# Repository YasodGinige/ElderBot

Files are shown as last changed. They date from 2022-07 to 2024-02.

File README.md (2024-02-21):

# ElderBot
### Elder Monitoring and Accident Warning System

In recent years, the risk of falling, especially among the aging population, has been propelled by the rising prevalence of various chronic diseases such as Alzheimer’s and Dementia along with the increasing incidence of chronic disorders such as diabetes, chronic obstructive pulmonary disease (COPD), cardiovascular diseases, etc. Implementation of fall detection systems is vital because falls are risky especially for individuals who live alone in their homes. According to the World Health Organization1, about 28% - 35% of individuals over the age of 65 are projected to go through one fall at a minimum each year, and this danger rises to 42% for individuals over the age of 70. Such a situation impels the necessity for fall detection systems. Fall detection systems can mitigate some of the adverse consequences of a fall. One major outcome of a fall is a bone fracture, for instance, a fracture of the hip, femur, forearm, leg, or ankle bone. Immediate medical intervention could effectively prevent serious deterioration of bodily functions. Through this project, we develop ElderBOT, a wearable fall detection device with an alert system that utilizes 3 modes of notifications in case of an emergency. Our product is a reliable, effective, and cost-efficient device designed to cater to user requirements.

Project video: https://drive.google.com/file/d/1kUZlkXkYoyiRHa6RiEkOUjJ5zr7rKidT/view

**Awards won**: IEEE IES Best Student Branch Chapter Competiton - second best project.                                    
                IEEE IHTC video competition award - Region 10 - 2nd place.

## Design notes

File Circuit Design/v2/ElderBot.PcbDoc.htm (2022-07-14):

Reporting Options

# File in Previous Format

Date | : | 3/1/2022
Time | : | 19:22:06
Filename | : | D:\ElderBot\Circuit_design\Ver_02_28\PCB\ElderBot.PcbDoc

Version | Warning

This file was generated by an earlier version of the software

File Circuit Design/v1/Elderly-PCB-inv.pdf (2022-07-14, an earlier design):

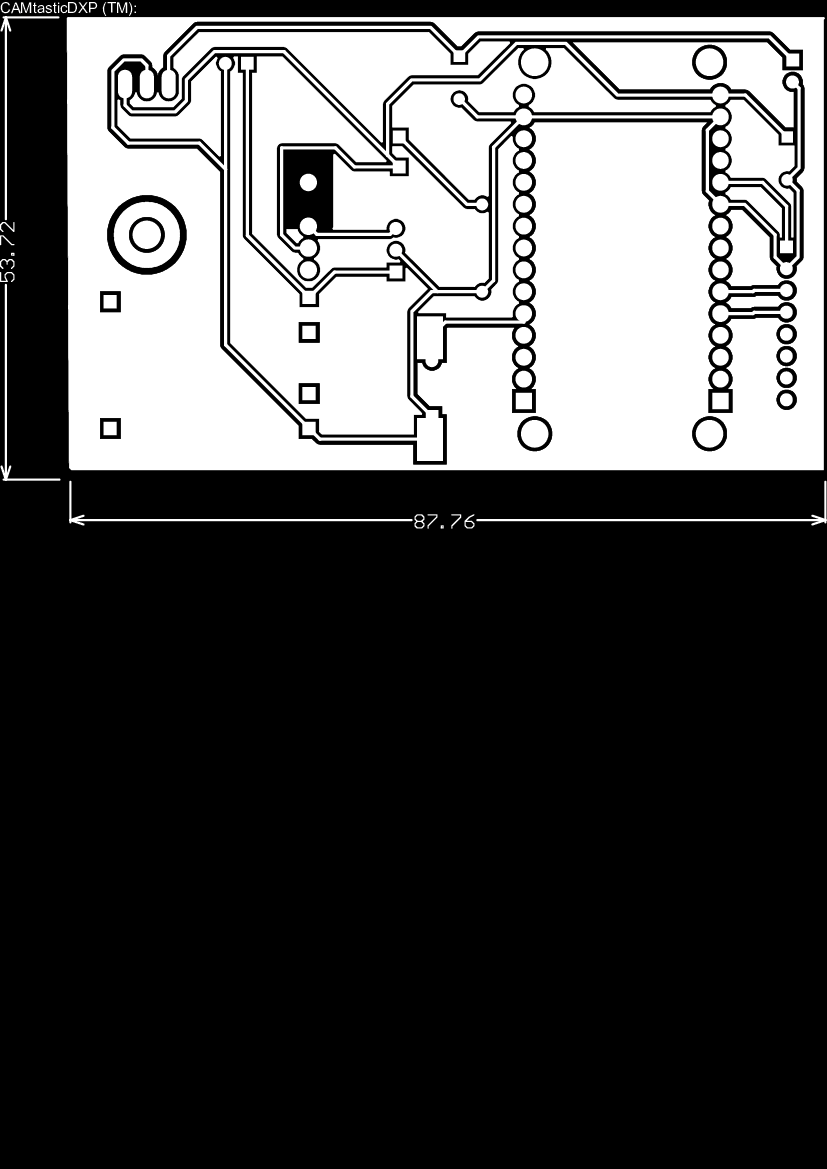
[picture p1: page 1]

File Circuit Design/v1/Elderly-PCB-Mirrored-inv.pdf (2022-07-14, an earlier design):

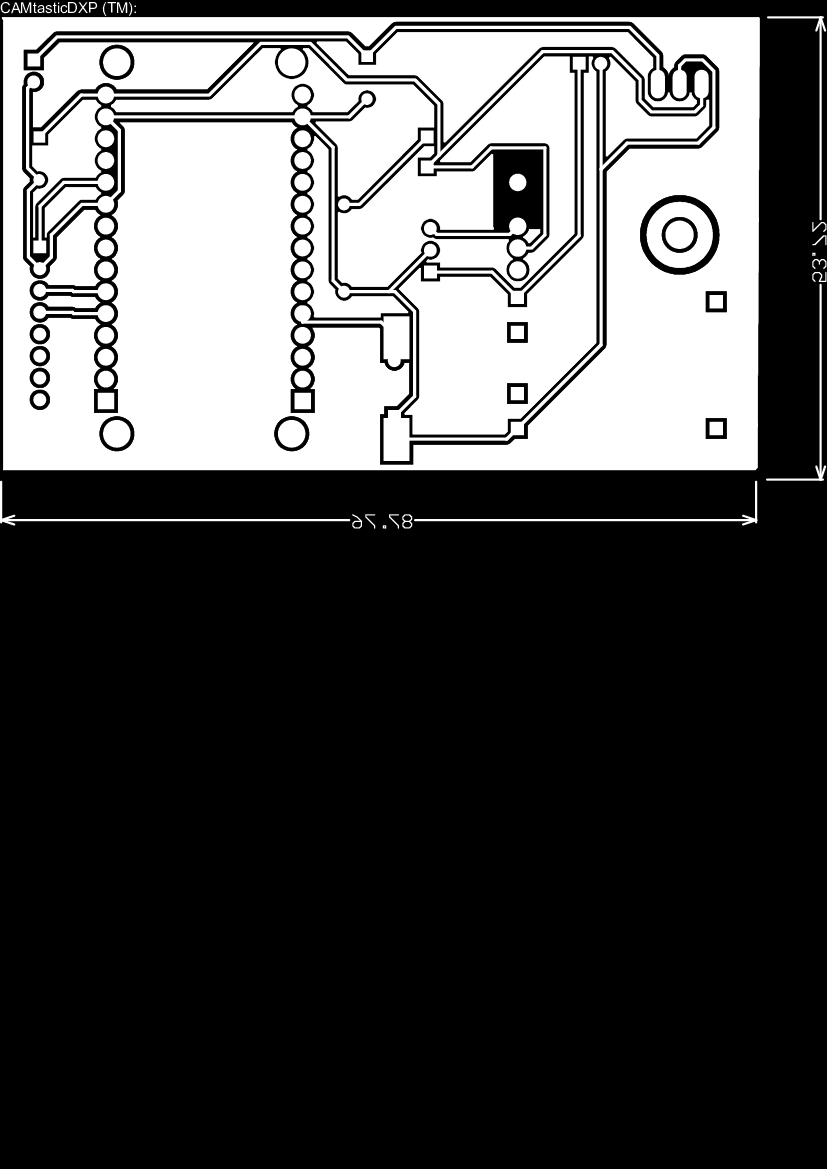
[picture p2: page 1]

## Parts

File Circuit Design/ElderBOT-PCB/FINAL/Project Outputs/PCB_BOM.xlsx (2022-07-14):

Line # | Name | Description | Designator | Quantity | Supplier 1 | Supplier Unit Price 1 | Supplier Subtotal 1
1 | NodeMCU | An open-source firmware and development kit that helps you to Prototype your IOT product within a few Lua script lines | A | 1 | https://lk-tronics.com/product/nodemcu-esp8266-ch340g-development-board/ | LKR 1700.00 | LKR 1700.00
2 | LED3 | Typical BLUE SiC LED | D1, D2, D3, D4 | 4 | https://scionelectronics.com/product/1206-blue-smd-led/ | LKR 3.00 | LKR 12.00
3 | Buzzer | Magnetic Transducer Buzzer | LS1 | 1 | https://www.digikey.com.au/en/products/detail/cui-devices/CMI-1295-0585T/10326184 | LKR 625.00 | LKR 625.00
4 | Resistor 1k +/-1% 1206 250 mW | Chip Resistor, 1 KOhm, +/- 1%, 0.25 W, -55 to 155 degC, 1206 (3216 Metric) | R1, R2, R3, R4, R5, R6, R7, R8 | 8 | https://www.mouser.com/ProductDetail/Vishay-Dale/RCC08051K00FKEA | LKR 80.00 | LKR 640.00
5 | Switch |  | S1 | 1 | https://www.digikey.com.au/en/products/detail/e-switch/EG1247/1804449?productid=1804449 | LKR 450.00 | LKR 450.00
6 | PushButton |  | S2 | 1 | https://www.amazon.com/QTEATAK-Momentary-Tactile-Button-Assortment/dp/B07VQF8P2Y | LKR 30.00 | LKR 30.00
7 | MPU6050 |  | U1 | 1 | https://nilambaraelectronics.com/product/gy-521-mpu6050-3-axis-analog-gyroscope/ | LKR 430.00 | LKR 430.00
8 | TP4056 |  | U2 | 1 | http://www.senith.lk/shop/item/1238/tp4056-lithium-ion-18650-battery-charger-module | LKR 180.00 | LKR 180.00
9 | SX1308 |  | U3 | 1 | https://www.aliexpress.com/item/1005001621801605.html | LKR 172.53 | LKR 172.53
Total |  |  |  |  |  |  | LKR 4239.53

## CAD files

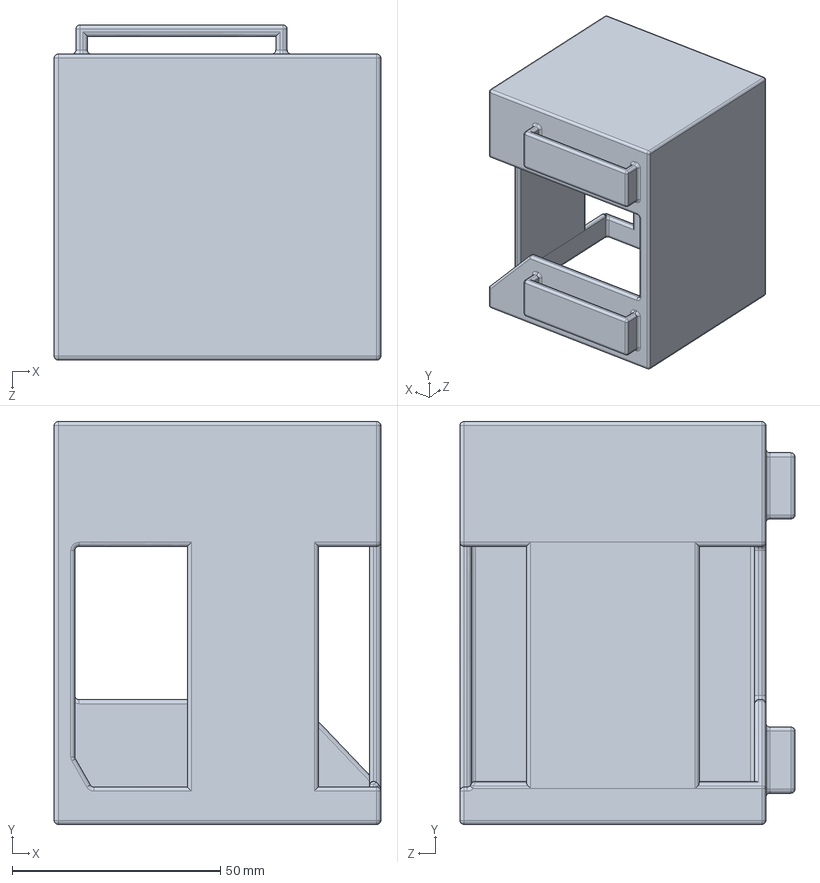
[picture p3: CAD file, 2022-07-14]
Enclosure Design/ElderBOT-Solidworks/outer cover1.SLDPRT
78.5 x 96.8 x 80.5 mm

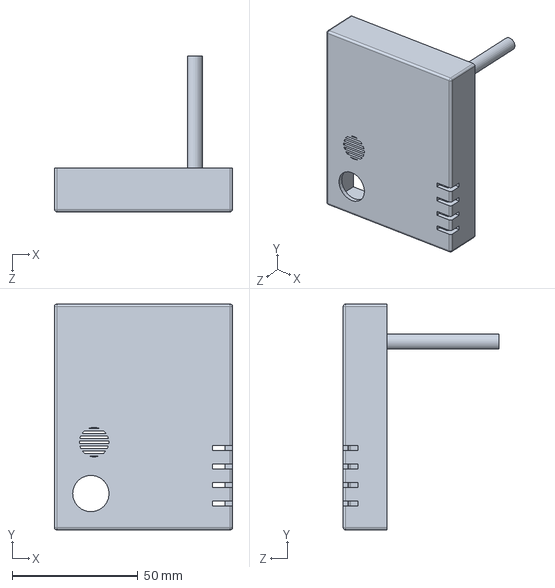
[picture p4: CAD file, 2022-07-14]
Enclosure Design/ElderBOT-Solidworks/upper_nail_lid_fixing_back2.SLDPRT
71.0 x 90.0 x 62.0 mm

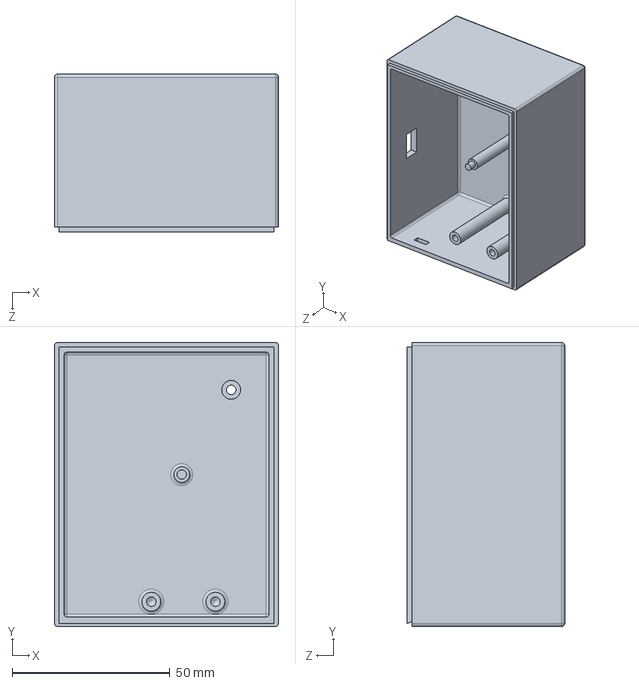
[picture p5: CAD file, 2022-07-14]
Enclosure Design/ElderBOT-Solidworks/bottom_nail_lid_fixing_back2.SLDPRT
71.0 x 90.0 x 50.0 mm

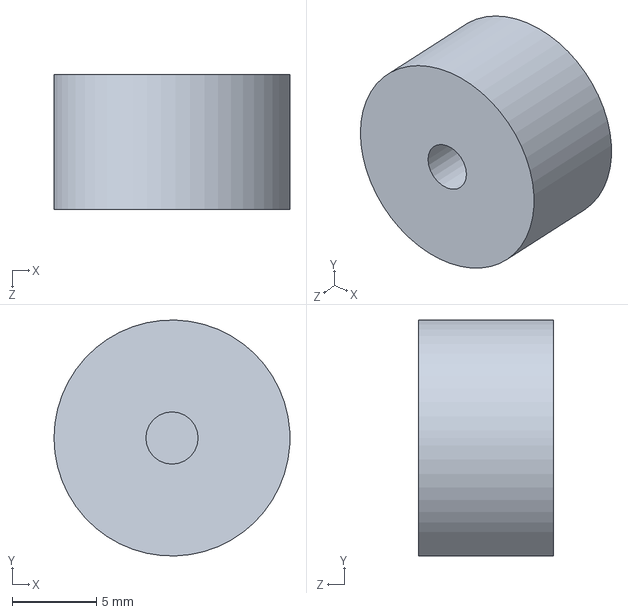
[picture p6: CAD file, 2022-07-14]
Enclosure Design/ElderBOT-Solidworks/push_button_cap_1.SLDPRT
14.0 x 14.0 x 8.00 mm

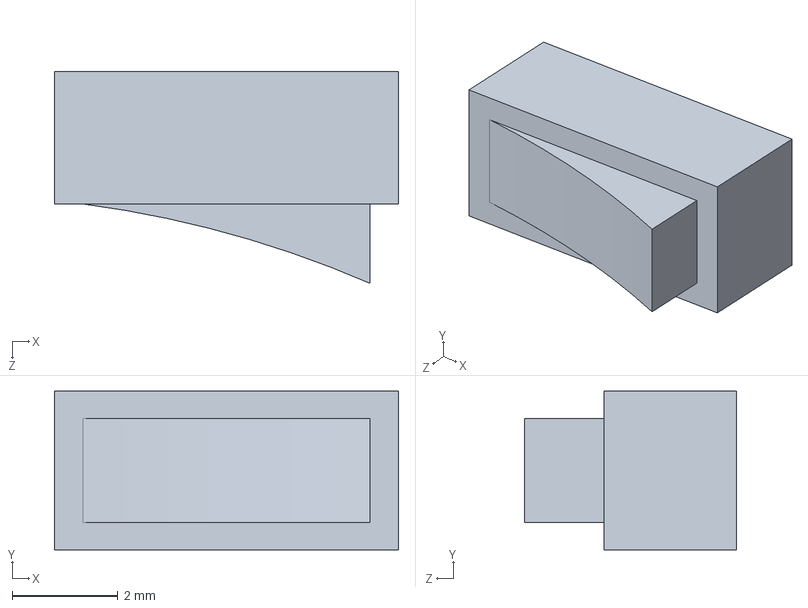
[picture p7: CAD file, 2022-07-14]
Enclosure Design/ElderBOT-Solidworks/switch.SLDPRT
6.50 x 3.00 x 4.00 mm

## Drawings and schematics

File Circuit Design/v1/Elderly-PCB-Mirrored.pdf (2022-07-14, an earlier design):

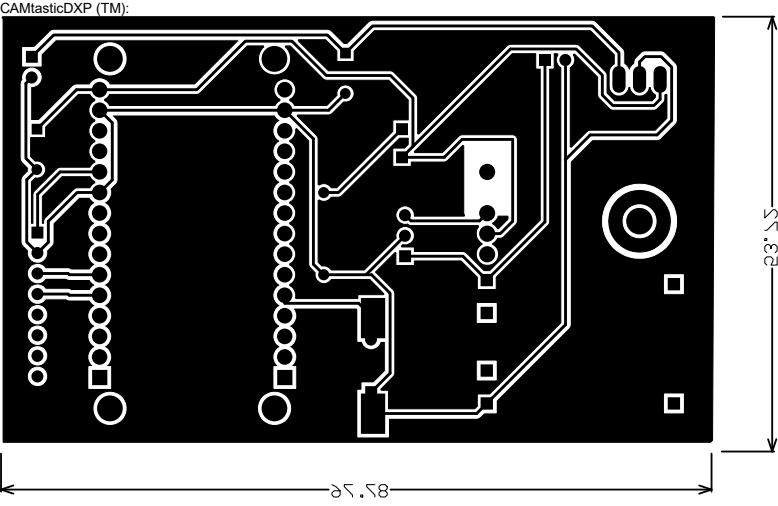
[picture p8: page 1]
CAMtasticDXP (TM):

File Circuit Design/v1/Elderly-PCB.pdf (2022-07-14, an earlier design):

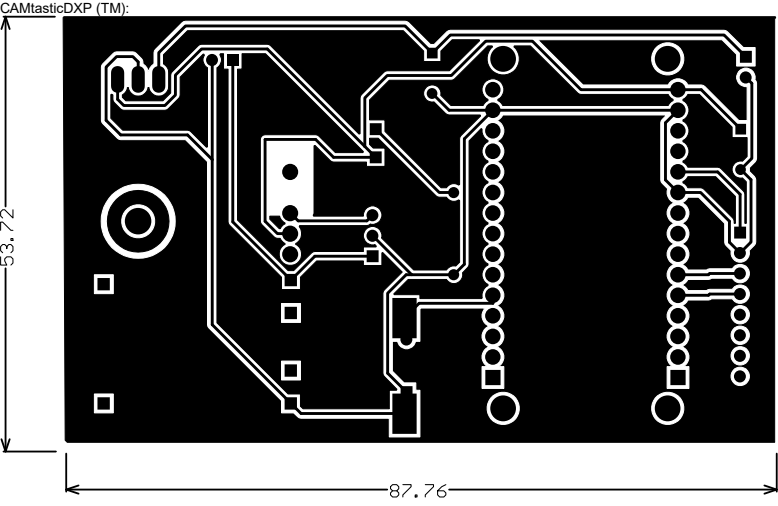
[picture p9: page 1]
CAMtasticDXP (TM):

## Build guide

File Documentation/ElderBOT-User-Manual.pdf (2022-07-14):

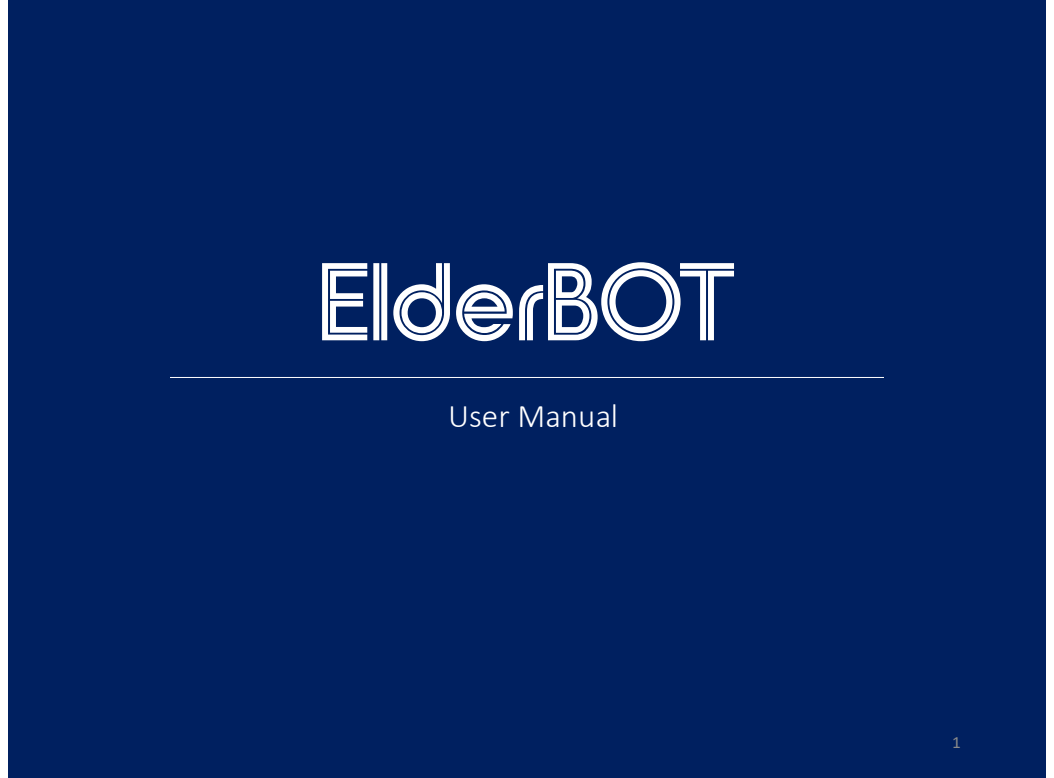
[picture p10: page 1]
User Manual

## Table of Contents

### 1. Warnings, care and use instructions 2. What’s in the box? 3. Intended use 4. Quick start

I. Registration
II. Wearing the device
III. Configuring the device IV. Modes

### 5. Technical Information 6. Troubleshooting 7. Disposal and replacement

2

## Warnings, care and use instructions

1. Please, read the user manual carefully before using the device. Check that everything is correct before using the system.

2. Use only accessories supplied and/or authorized by the manufacturer 3. The product must be repaired by authorized staff by the manufacturer 4. Equipment modifications must be done by authorized staff by manufacturer 5. Do not expose the system to liquids. Liquid exposure may permanently damage the

system.
6. The box is closed and should only be opened by qualified personnel.
7. Do not use the system under 0ºC conditions or over 40ºC. Wait at least two hours for the system to return to room temperature before it is turned on. Operate system with room humidity between 45% and 85%.
8. Do not put metallic elements on the device.

### 9. Do not use with inflammable agents 10. Manufacturers recommend not to sleep with the sensor since it can be oppressive and

might cause physiological discomfort.
11. Do not use the sensor in medical interventions (surgical procedures, X-ray sessions, magnetic resonances…).
12. Limited warranty covers any defect in the device under normal use during warranty period (2 years). Warranty does not cover any problem that is caused by conditions, malfunctioning or damage not resulting from normal use. It is not allowed to open the enclosure, otherwise, Limited warranty will not be applied

3

## What’s in the box?

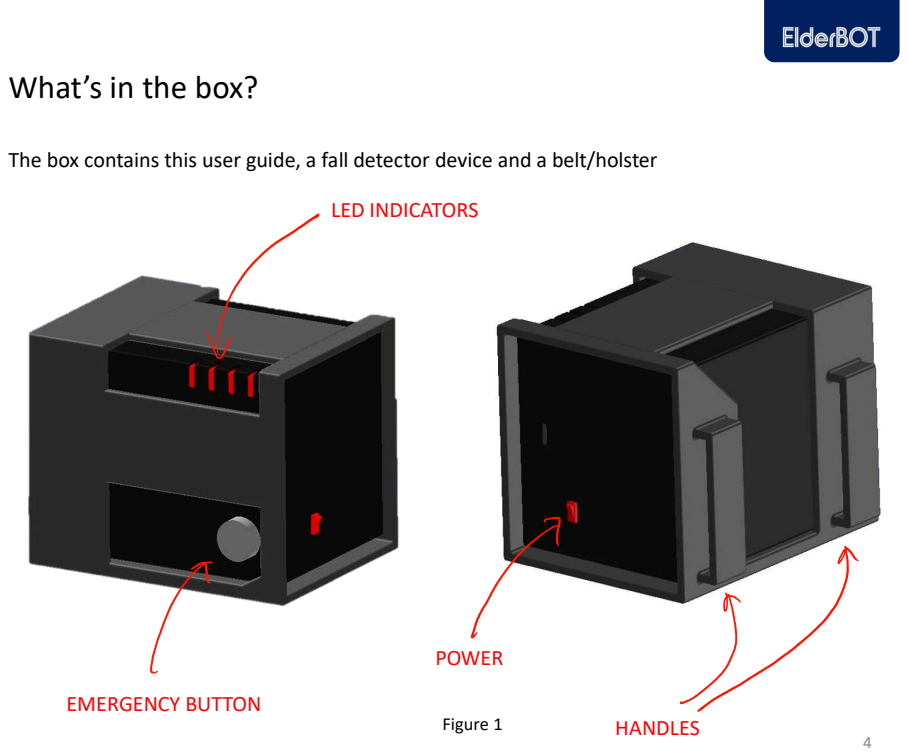
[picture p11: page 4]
LED INDICATORS; POWER; HANDLES; EMERGENCY BUTTON; Figure 1

The box contains this user guide, a fall detector device and a belt/holster

5

## Intended use

There are 3 modes of our device, which will trigger different notifications.

Fall Mode
Fall When an user falls, the device will detect whether a fall occurred according to ElderBOT’s algorithm. After confirmation, a message will be sent to the guardian informing the situation of the user.

“ElderBOT warning for User! Device has detected fall incident. No response from the user. Please try contacting them and see if they are safe.”

Normal Mode
If the change in motion is not confirmed to be a fall either by the algorithm, or by the user by manually turning the alarm off ("Normal" mode), no message will be sent.

Emergency Mode
You can also trigger the device manually to alert your guardians by pressing the emergency button (see Figure 1).

“ElderBOT warning for User! User has manually started emergency mode. Please try contacting them and see if they are safe.”

6

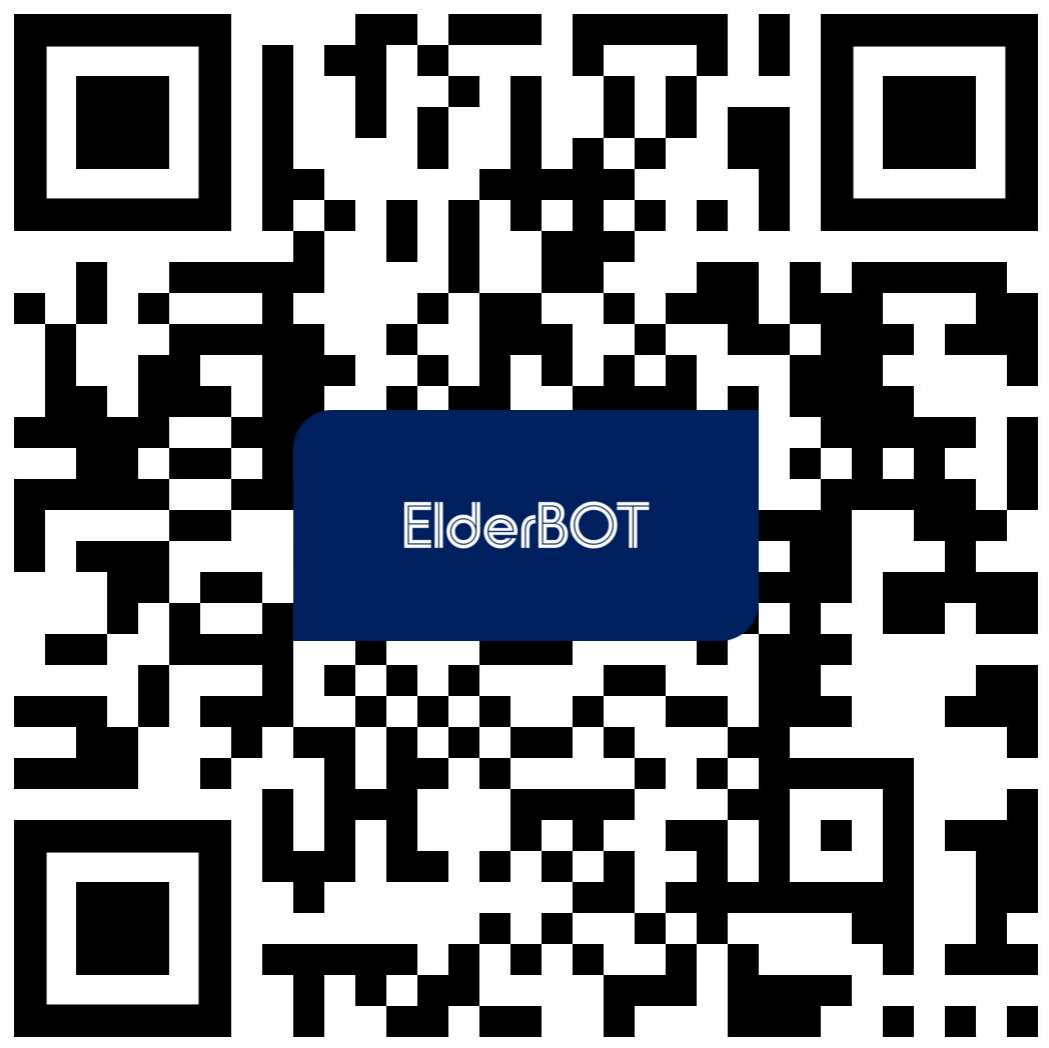
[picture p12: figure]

Please use the QR code or go to: http://3.137.154.119:8080/

## Quick start-

Registration

If you are using the device for the first time, select the
Sign Up option on the homepage. If you already have an account, select the Login option to proceed.

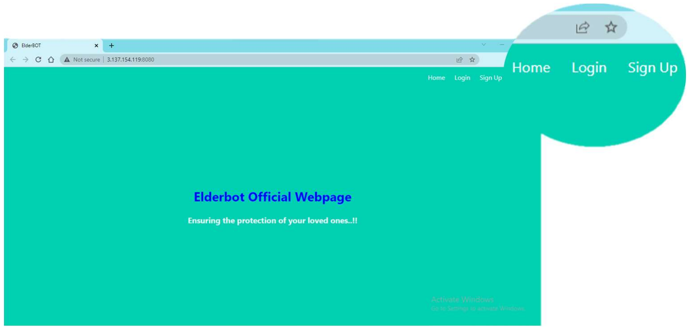
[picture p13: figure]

Figure 2

## Quick start

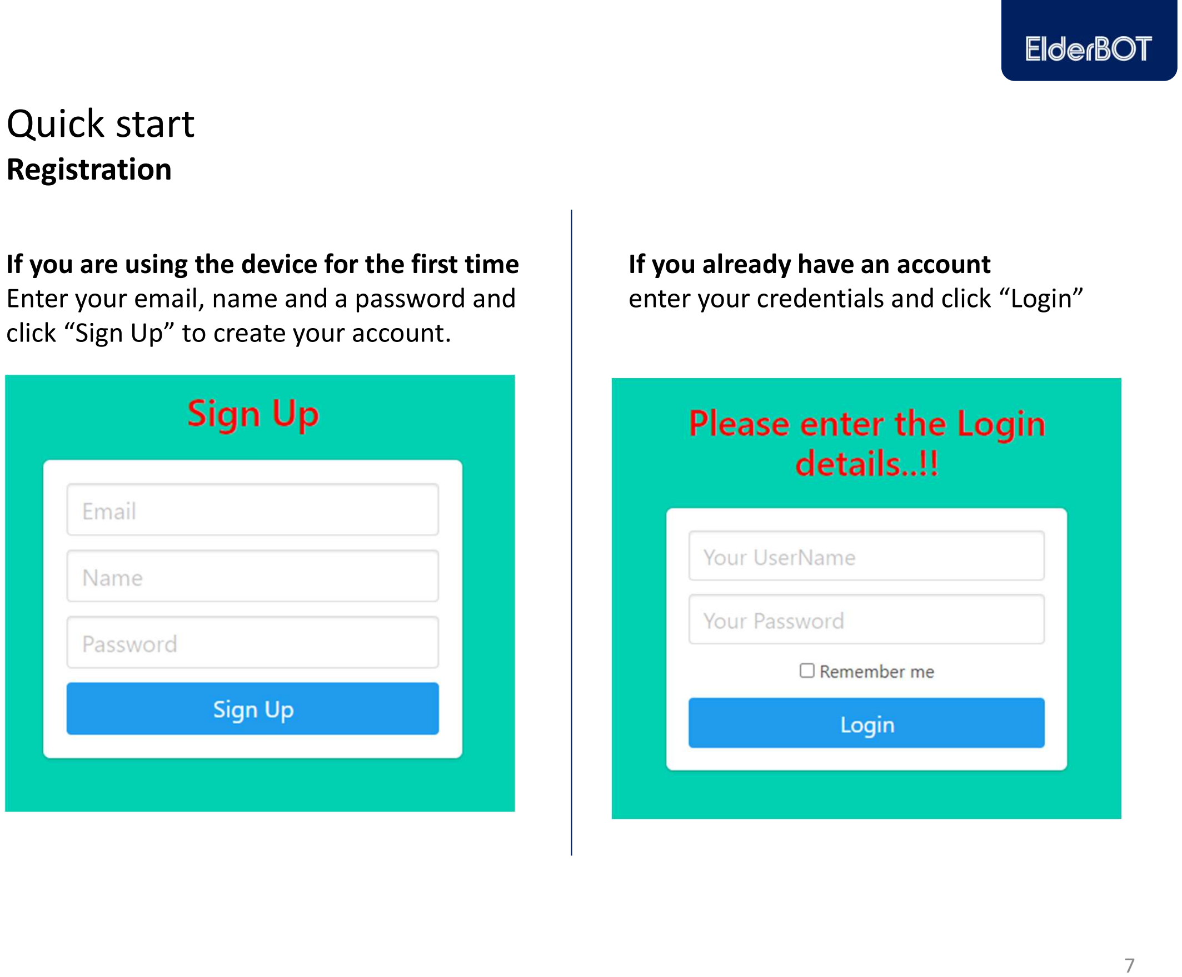
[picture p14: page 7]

7

If you are using the device for the first time Enter your email, name and a password and click “Sign Up” to create your account.

Registration

If you already have an account
enter your credentials and click “Login”

8

- Clip the device to your belt or clothing in
the upright position as shown below. • | ElderBOT will only detect you falling if you
are wearing it. • | The device must be worn at or above the

waist, where it will detect the maximum
number of falls. • | When removing the fall detector, handle
carefully to avoid false notifications. • | Due to the complex dynamics of falling, all

falls may not be detected. In the event of a fall not being detected the manual button can still be used to call for help
- It is not recommended that you wear the fall detector whilst in bed, as normal movement in bed may cause the fall detector to trigger

## Quick start

Wearing the device

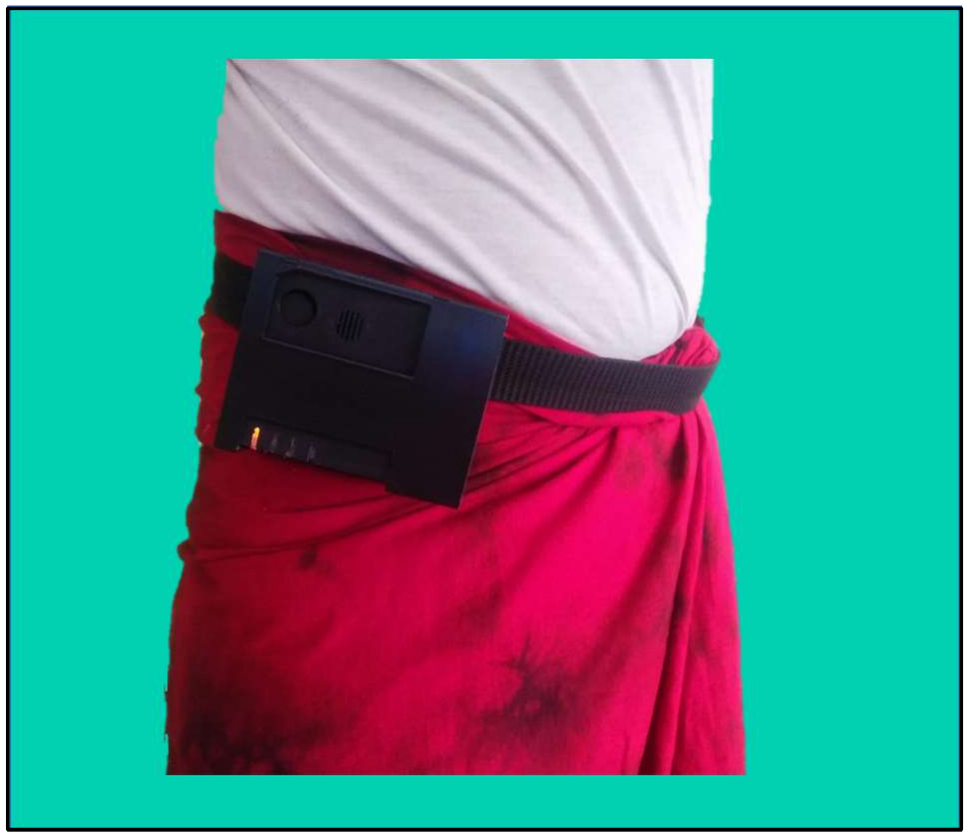
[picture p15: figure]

Figure 3

9

If you are using the device for the first time:

## Quick start

Configuring the device

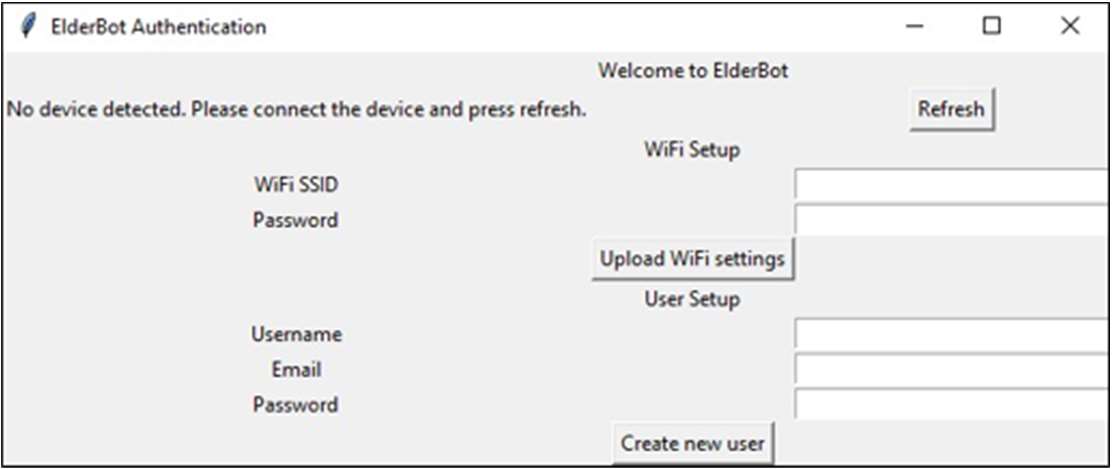
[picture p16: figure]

Figure 4
- Check if the device is detected.
- Type in the SSID and Password of the WIFI network that the device is connected to. Afterwards, click 'Upload Wi-Fi settings'
- Fill in your ElderBOT account details: Username, email and password for login
- Then select a 'Create new user' to create your new account

## A- Power Indicator

## Quick start

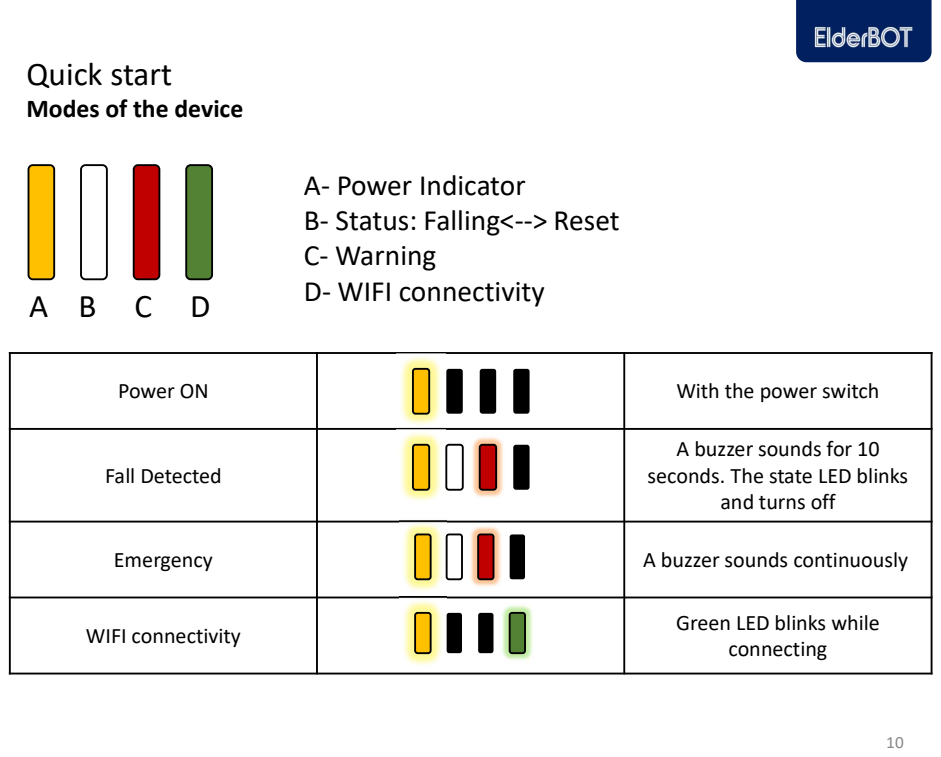
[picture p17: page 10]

Modes of the device

B- Status: Falling<--> Reset
C- Warning
D- WIFI connectivity

Power ON | With the power switch

Fall Detected | A buzzer sounds for 10 seconds. The state LED blinks and turns off

Emergency | A buzzer sounds continuously

WIFI connectivity | Green LED blinks while connecting

11

## Technical information

Weight: 210g
Dimensions: 95 x 72 x 63 mm (WxHxD)
Battery: WZS 18650 3.7V Rechargeable Lithium Ion
Battery Life: 300 charge cycles
Radio frequency: 869.2125MHz, compliant with the European Social Alarm frequency band

Environmental Temperature: Operating temperature (to perform to full specification) = 10°C to 35°C, storage = 15°C to 40°C
Humidity: Operating relative humidity (non-condensing to perform to full specification) = 0 to 80%, storage relative humidity (non-condensing) = 0 to 93%

Standards We Strive to Achieve

Software and Firmware updates: IEC 62304:
Risk assessment and management: ISO 14971 Lifecycle design: ISO 14971
EMC: EN50130-4: 1995
Design and Manufacture: ISO9001:2008

12

Troubleshooting • ElderBOT authentication is not successful.

Check if the device is properly detected by checking the device status in the authenticator window. (Figure 5). If the device is not detected, try turning the device OFF and turn back ON after a few minutes.

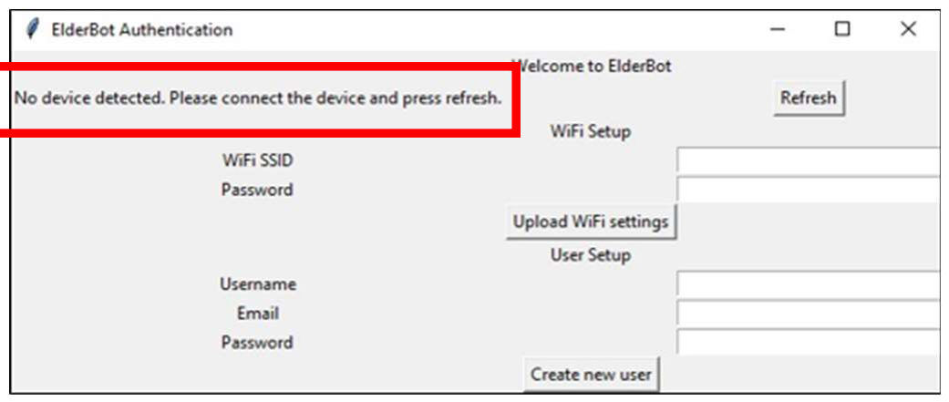
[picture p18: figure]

Figure 5
- The device does not turn ON.

Check the batteries and charge the device. If unsuccessful, contact the manufacturer or seek local technical support.

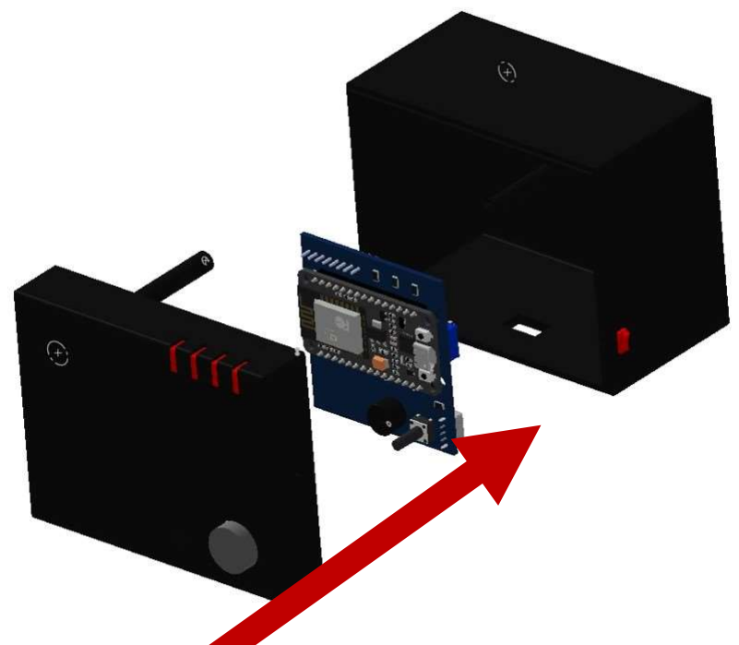
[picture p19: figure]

13

## Disposal and Replacement: • To replace the battery

1) To access the battery, remove the enclosure cover screw
2) Remove the battery cover by sliding it in the opposite direction of the
3) Remove the battery and replace it with the new battery (WZS 18650 3.7V Li-ion), remember to observe the correct orientation.
4) Replace the sliding cover and the screw. Test the fall detector by making a manual call. Inform the operator that you are making a battery test call.
5) If the device fails to make a test call, then check the orientation of the
battery. If this is correct, then contact your supplier.
NOTE: Dispose of used batteries in accordance with the latest local legislation. Do not dispose of in household waste. • To dispose the device:

Affixed to this device in accordance with Central Environmental Authority Directives. These directives call for the separate collection and disposal of electrical and electronic equipment. Sorting such waste and removing it from other forms of waste lessens the contribution of potentially toxic substances into municipal disposal systems and into the larger ecosystem. Please, return to ElderBOT INC. Or your local vendor at the end of its operating life.

Figure 6

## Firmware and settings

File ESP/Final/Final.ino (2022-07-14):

#include "FS.h"
#include <ESP8266WiFi.h>
#include <WiFiClient.h>
#include <PubSubClient.h>
#include <NTPClient.h>
#include <WiFiUdp.h>
#include <stdio.h>
#include <string.h>
#include <cstring>
#include <Adafruit_MPU6050.h>
#include <Adafruit_Sensor.h>
#include <Wire.h>

char msg[256];

Adafruit_MPU6050 mpu;
sensors_event_t a,g,temp;

char* ssid = "vivo1727"; //"NOSSID";
char* password = "12345678"; //"NOPASSWORD";
bool needWiFi = false; //true
char* username = "TestUser";
char* deviceId = "Pamu_ESP"; // Must be 8 letters

String deviceId_Per="Pamu_ESP";
String Type="None";
String MSG="None";
bool New_Message=false;
char* Status="Normal";
String Resp_UserApp="";
String Medic="";

int buzzer = 9;
int button = 3;

int wifi_LED = 12;
int status_LED = 13;
int emergency_LED = 2;

WiFiUDP ntpUDP;
NTPClient timeClient(ntpUDP, "pool.ntp.org");
WiFiClientSecure espClient;

const char* AWS_endpoint = "a3diuj9r5yc78a-ats.iot.us-east-2.amazonaws.com";

String getValue(String data, char separator, int index)
{
    int found = 0;
    int strIndex[] = { 0, -1 };
    int maxIndex = data.length() - 1;
    for (int i = 0; i <= maxIndex && found <= index; i++) {
        if (data.charAt(i) == separator || i == maxIndex) {
            found++;
            strIndex[0] = strIndex[1] + 1;
            strIndex[1] = (i == maxIndex) ? i+1 : i;
        }
    }
    return found > index ? data.substring(strIndex[0], strIndex[1]) : "";
}

void callback(char* topic, byte* payload, unsigned int Length) {                     // Take the incomming MQTT Messages and update NodeMCU global variables
  String Data_in = "";
  for (int i = 1; i < Length-1; i++) {
    Data_in += (char)payload[i];
  }
  deviceId_Per = getValue(Data_in, ',', 0);
  Type = getValue(Data_in, ',', 1);
  MSG = getValue(Data_in, ',', 2);
  New_Message = true;
  digitalWrite(buzzer, HIGH); delay(10); digitalWrite(buzzer, LOW); delay(10);
  digitalWrite(buzzer, HIGH); delay(10); digitalWrite(buzzer, LOW); delay(10);
  digitalWrite(buzzer, HIGH); delay(10); digitalWrite(buzzer, LOW); delay(10);
}

PubSubClient client(AWS_endpoint, 8883, callback, espClient);

bool initWifi() {                                                                            // Reinitializing WiFi connectivity after awaking
  WiFi.begin(ssid, password); delay(500);
  int count=0;
  while((count<1000) && (WiFi.status()!=WL_CONNECTED)){digitalWrite(wifi_LED,HIGH);delay(25);digitalWrite(wifi_LED, LOW);delay(25);count++;} 
  delay(500);
  return WiFi.status()==WL_CONNECTED ? true : false;
 }

bool initTime() {
  timeClient.begin();
  int count=0;
  while ((count<1000) && (!timeClient.update())) {timeClient.forceUpdate(); digitalWrite(wifi_LED,HIGH);delay(25);digitalWrite(wifi_LED, LOW);delay(25);count++;}
  if (count<1000) {espClient.setX509Time(timeClient.getEpochTime()); return true;}
  else return false;
}

void reconnect() {
  while (!client.connected()) {
    if (client.connect(deviceId)) {
      snprintf(msg, 256, "{\"dev\": \"%s\", \"t\": \"Connection Established\"}", deviceId);
      client.publish("outTopic", msg);
      client.subscribe("inTopic");
    } else {
      delay(5000);
    }
  }
}

bool setupAWS(){
  delay(1000);
  if (!SPIFFS.begin()) {return false;}

  File cert = SPIFFS.open("/cert.der", "r");
  if (!cert) return false;
  delay(1000);
  if (!espClient.loadCertificate(cert)) return false;

  File private_key = SPIFFS.open("/private.der", "r");
  if (!private_key) return false;
  delay(1000);
  if (!espClient.loadPrivateKey(private_key)) return false;

  File ca = SPIFFS.open("/ca.der", "r");
  if (!ca) return false;
  delay(1000);
  if (!espClient.loadCACert(ca)) return false;

  return true;
}

float acclx = 0;
float accly = 0;
float acclz = 0;
float gyrox = 0;
float gyroy = 0;
float gyroz = 0;

float alpha = 0.95;
float accPrev = 0;
float aXPrev = 0;
float aYPrev = 0;
float aZPrev = 0;
float gXPrev = 0;
float gYPrev = 0;
float gZPrev = 0;

float accThresh = 5;
float gXThresh = 1.5;
float gYThresh = 1.5;
float gZThresh = 1.5;
float gMin = 0.1;

bool makeDecision(float aX, float aY, float aZ, float gX, float gY, float gZ){
  // calibrate readings
  aX = alpha * aX + (1 - alpha) * aXPrev;
  aY = alpha * aY + (1 - alpha) * aYPrev;
  aZ = alpha * aZ + (1 - alpha) * aZPrev;

  // threshold to avoid random changes
  if (abs(gX-gXPrev) > gMin){
    gX = alpha * gX + (1 - alpha) * gXPrev;
  } else{
    gX = gXPrev;
  }
  if (abs(gY-gYPrev) > gMin){
    gY = alpha * gY + (1 - alpha) * gYPrev;
  } else{
    gY = gYPrev;
  }
  if (abs(gZ-gZPrev) > gMin){
    gZ = alpha * gZ + (1 - alpha) * gZPrev;
  } else{
    gZ = gZPrev;
  }
  // Calculate acceleration
  float acc = sqrt(sq(aX) + sq(aY) + sq(aZ));
  float accChange = abs(acc - accPrev);
  accPrev = acc;

  // calculate gyro change
  float gXChange = abs(gX - gXPrev);
  float gYChange = abs(gY - gYPrev);
  float gZChange = abs(gZ - gZPrev);

  // decision
  bool decision = false;
  if (accChange > accThresh){
    if (gXChange > gXThresh){
      decision = true;
    } 
    else if(gYChange > gYThresh){
      decision = true;
    }
    else if (gZChange > gZThresh){
      decision = true;
    }
  }

  aXPrev = aX; aYPrev = aY; aZPrev = aZ; gXPrev = gX; gYPrev = gY; gZPrev = gZ;
  
  return decision;
}

long lastMsg = 0;

bool check_emergency(){
  if (digitalRead(button)==false) {
    delay(2000);
    if (digitalRead(button)==false){
      digitalWrite(buzzer,HIGH); delay(100); digitalWrite(buzzer,LOW);
      Status="Emergency";
      snprintf(msg,256, "{\"dev\": \"%s\", \"t\": \"Fallen\"}", deviceId);
      client.publish("outTopic", msg);
    }
  }
}  

void setup() {
  pinMode(status_LED, OUTPUT);
  pinMode(wifi_LED, OUTPUT);
  pinMode(emergency_LED, OUTPUT);
  pinMode(buzzer, OUTPUT);
  pinMode(button, INPUT_PULLUP);
  digitalWrite(status_LED, LOW);
  digitalWrite(wifi_LED, LOW);
  digitalWrite(emergency_LED, LOW);
  digitalWrite(buzzer, LOW);
  setupAWS();
  while (!mpu.begin()){
    digitalWrite(status_LED,LOW);
    delay(250);
    digitalWrite(status_LED,HIGH);
    delay(250);
  }
  digitalWrite(status_LED, HIGH);
  mpu.setAccelerometerRange(MPU6050_RANGE_2_G);
  mpu.setGyroRange(MPU6050_RANGE_500_DEG);
  mpu.setFilterBandwidth(MPU6050_BAND_21_HZ);
  initWifi();
  initTime();
}

long fallTime = 0;

void loop() {
  if (!needWiFi) {
    digitalWrite(status_LED, HIGH);
    if (!client.connected()) reconnect();
    client.loop();

    long now = millis();
    if (now - lastMsg > 250 and Status=="Normal"){
      lastMsg = now;
      mpu.getEvent(&a, &g, &temp);
      acclx = a.acceleration.x;
      accly = a.acceleration.y;
      acclz = a.acceleration.z;
      gyrox = g.gyro.x;
      gyroy = g.gyro.y;
      gyroz = g.gyro.z;
      bool decision = makeDecision(acclx, accly, acclz, gyrox, gyroy, gyroz);
      if (decision) {
        snprintf(msg, 256, "{\"dev\": \"%s\", \"t\": \"Fallen\"}", deviceId);
        digitalWrite(buzzer, HIGH); delay(100); digitalWrite(buzzer, LOW);
        client.publish("outTopic", msg);
        Status="Fallen"; digitalWrite(emergency_LED, HIGH);
        fallTime = millis();
      }
    }

    if (Status=="Fallen confirmed" or Status=="Emergency") {
      digitalWrite(emergency_LED, HIGH);
      digitalWrite(buzzer,HIGH); delay(900);
      digitalWrite(buzzer,LOW); delay(100);
    } else if (Status=="Fallen") {
      if ((millis()-fallTime) > 10000){
        Status="Fallen confirmed";
        snprintf(msg, 256, "{\"dev\": \"%s\", \"t\": \"Fallen\"}", deviceId);
        digitalWrite(buzzer, HIGH); delay(100); digitalWrite(buzzer, LOW);
        client.publish("outTopic", msg);
      }
      else if (digitalRead(button)==false) {
        delay(2000);
        if (digitalRead(button)==false){
          snprintf(msg, 256, "{\"dev\": \"%s\", \"t\": \"Normal\"}", deviceId);
          client.publish("outTopic", msg);
          Status="Normal"; digitalWrite(emergency_LED, LOW); fallTime=millis();
        }
      }
      digitalWrite(emergency_LED, HIGH);
      digitalWrite(buzzer,HIGH); delay(100);
      digitalWrite(buzzer,LOW); delay(100);
    } else if (Status=="Normal") {
      check_emergency(); digitalWrite(emergency_LED, LOW);
    }

    if (New_Message){
      if (Type=="Medication"){
        Medic=MSG;
        int cnt_medic = 0;
        while (cnt_medic<60 or digitalRead(button)==true){
          digitalWrite(buzzer,HIGH); delay(50); digitalWrite(buzzer,LOW); delay(50);
          digitalWrite(buzzer,HIGH); delay(50); digitalWrite(buzzer,LOW); delay(350);
          cnt_medic++;
        }
        if (cnt_medic==60) {
          snprintf(msg, 256, "{\"dev\": \"%s\", \"t\": \"Medication misseed\"}", deviceId);
          client.publish("outTopic", msg);
        }
        New_Message=false;
        digitalWrite(buzzer,LOW);
        }

      else if (Type=="Warning"){
        New_Message=false;
       }
    }
    digitalWrite(emergency_LED, HIGH); delay(100); digitalWrite(emergency_LED, LOW);
  }
  
  else digitalWrite(status_LED, LOW);
}

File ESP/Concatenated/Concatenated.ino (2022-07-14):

#include "FS.h"
#include <ESP8266WiFi.h>
#include <WiFiClient.h>
#include <PubSubClient.h>
#include <NTPClient.h>
#include <WiFiUdp.h>
#include <stdio.h>
#include <string.h>
#include <cstring>

char* ssid = "NOSSID";
char* password = "NOPASSWORD";
char* UserInfo ="";
bool needWiFi = true;
char str[32] = { 0 };
String Data;
const char* AWS_endpoint = "a3diuj9r5yc78a-ats.iot.us-east-2.amazonaws.com";
long lastMsg = 0;
char msg[50];
char* Sens_Read="0";
char* Status="Normal";             // States: Normal / Fallen / Emergency
int value=0;


const char* D2S = "D2S";
const char* S2D = "S2D";

String Device_ID_Per="Yasod_ESP";
String Device_ID="0";
String Type="None";
String MSG="None";
bool New_Message=true;

String Resp_UserApp="";
String Medic="";


int Buzzer=6;
uint8_t Emergency = D3;


WiFiUDP ntpUDP;
NTPClient timeClient(ntpUDP, "pool.ntp.org");
WiFiClientSecure espClient;


void callback(char* topic, byte* payload, unsigned int Length) {                     // Take the incomming MQTT Messages and update NodeMCU global variables
  String Data_in = "";
  for (int i = 0; i < Length; i++) {
    Data_in += (char)payload[i];
  }
    Device_ID = getValue(Data_in, ',', 0);
    Type = getValue(Data_in, ',', 1);
    MSG = getValue(Data_in, ',', 2);
  
    char msgr[30]="MQTT receievd";
    Serial.println(msgr);
    
}

PubSubClient client(AWS_endpoint, 8883, callback, espClient);

/*void callback(char* topic, byte* payload, unsigned int Length) {
  Serial.print("Message arrived: [");
  Serial.print(topic);
  Serial.print(": ");
  for (int i=0; i<Length; i++){
    Serial.print((char)payload[i]);
  }
  Serial.println("]");
}*/


void setupWiFi(){
  delay(10);

  espClient.setBufferSizes(512, 512);
  Serial.println();
  Serial.print("Connecting to ");
  Serial.print(ssid);

  WiFi.begin(ssid, password);
  while (WiFi.status() != WL_CONNECTED){delay(500); Serial.print(".");}

  Serial.println("");
  Serial.println("WiFi connected");

  timeClient.begin();
  while (!timeClient.update()) {timeClient.forceUpdate();}

  espClient.setX509Time(timeClient.getEpochTime());
}

void reconnect() {
  while (!client.connected()) {
    Serial.print("Attempting MQTT connection...");
    if (client.connect("YasodESP")) {
      Serial.println("connected");
      //client.publish("D2S", "MQTT Connected");
      client.subscribe("S2D");
    } else {
      Serial.print("failed, rc=");
      Serial.print(client.state());
      Serial.println(" try again in 5 seconds");

      char buf[256];
      espClient.getLastSSLError(buf, 256);
      Serial.print("WiFiClientSecure SSL error: ");
      Serial.println(buf);
      delay(5000);
    }
  }
}

bool initWifi() {                                                                            // Reinitializing WiFi connectivity after awaking
  WiFi.begin(ssid, password);
  delay(500);
  int count=0;
  while((count<50) && (WiFi.status()!=WL_CONNECTED)){digitalWrite(16,HIGH);delay(30);digitalWrite(16, LOW);delay(30);count++;} 
  return WiFi.status()==WL_CONNECTED ? true : false;
 }

bool getWiFi(){
  while (!Serial.available());
  Data = Serial.readString();
  int n = Data.length();
  char str[n+1];
  strcpy(str, Data.c_str());
  char *pch;
  pch = strtok(str, " \n");
  ssid=pch;
  pch = strtok(str, " \n");
  password=pch;
  pch = strtok(str, " \n");
  UserInfo=pch;                       // UserInfo is Char. Storage Capacity of Char is a problem here ???????????????????????????????????????

  
  
  digitalWrite(16, LOW);
  if (initWifi()) {digitalWrite(16, HIGH); Serial.write("Success"); needWiFi=false;}
  else {digitalWrite(16, HIGH); Serial.write("Error");}
  delay(2000);
}



String getValue(String data, char separator, int index)
{
    int found = 0;
    int strIndex[] = { 0, -1 };
    int maxIndex = data.length() - 1;
    for (int i = 0; i <= maxIndex && found <= index; i++) {
        if (data.charAt(i) == separator || i == maxIndex) {
            found++;
            strIndex[0] = strIndex[1] + 1;
            strIndex[1] = (i == maxIndex) ? i+1 : i;
        }
    }
    return found > index ? data.substring(strIndex[0], strIndex[1]) : "";
}



void IntCallback(){
  if (*Status=='Emergency'){
    Status="Normal";
  }

  else{
    char D_ID[32];
    Device_ID_Per.toCharArray(D_ID, 32);
    snprintf(msg, 75, "{\"E-mes\": \"Emergency Situation on Device #%c\"}", D_ID);
    Serial.print("Publish message: "); Serial.println(msg);
    client.publish("D2S", msg);
    Status="Emergency";
    Serial.print("Heap: "); Serial.println(ESP.getFreeHeap()); 
  }
  
}


void setup() {
  pinMode(2, OUTPUT);
  pinMode(16, OUTPUT);
  pinMode(Buzzer,OUTPUT);
  digitalWrite(2, HIGH);
  digitalWrite(16, HIGH);
  Serial.begin(115200);

  attachInterrupt(digitalPinToInterrupt(Emergency), IntCallback, RISING);
}
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
